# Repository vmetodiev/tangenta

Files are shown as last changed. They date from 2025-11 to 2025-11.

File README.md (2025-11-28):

# Tangenta
Micro ATX motherboard for Toradex Verdin iMX8M Mini

# Alternative Idea
To be used as a base for developing mATX motherboards for other (similar) SoMs.

# Project Features

## USB (via Microchip hub)
- 3x USB ports exposed on the rear panel - for mouse, keyboard, storage drive
- 1x USB port connects to an M.2 slot with a SIM card (for a mobile modem)

## HDMI
- LVDS to HDMI via Lontium

## Ethernet (via Realtek switch)
- 3x RJ-45 with integrated magnetics (1000BASE-T)
- 1x SFP (1000BASE-X)

## PCIe (via Pericom switch)
- 2x PCIe slots (full-length x16, operating at x1 speed, Gen 2)
- 1x M.2 slot for SSD expansion (operating at x1 speed, Gen 2)

## Industrial Connectivity
- 2x Isolated CAN transceivers
- 1x Isolated RS-422 transceiver (could be used as RS-485 as well)

All of the above exposed over a single RJ-45 connector (to fit the maximum allowed ATX rear panel lenght)

# A few images
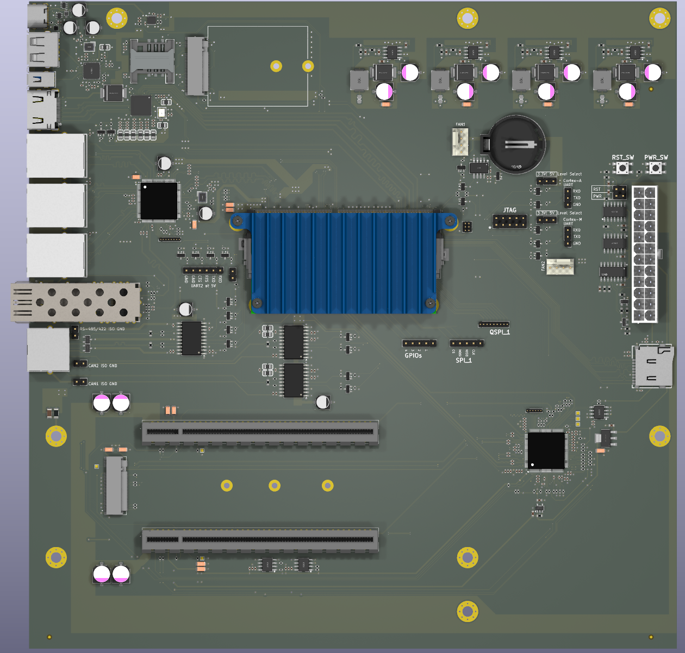
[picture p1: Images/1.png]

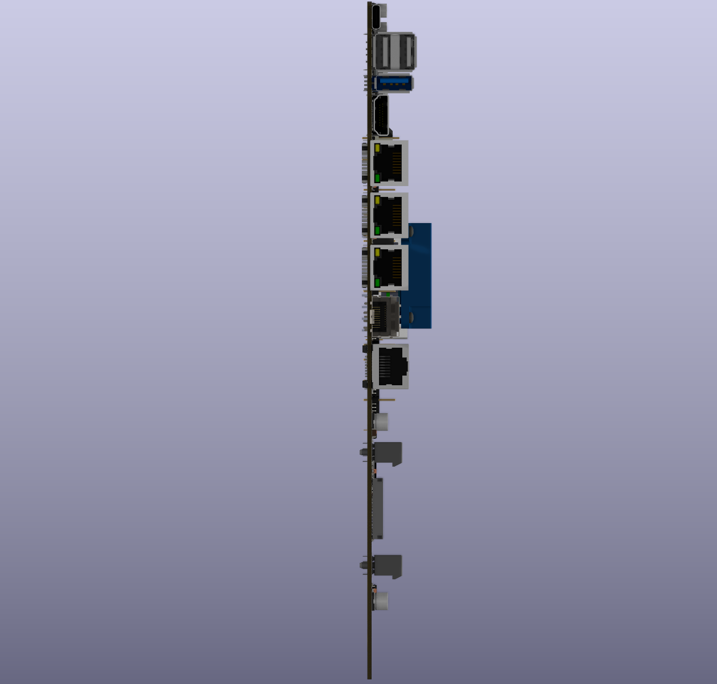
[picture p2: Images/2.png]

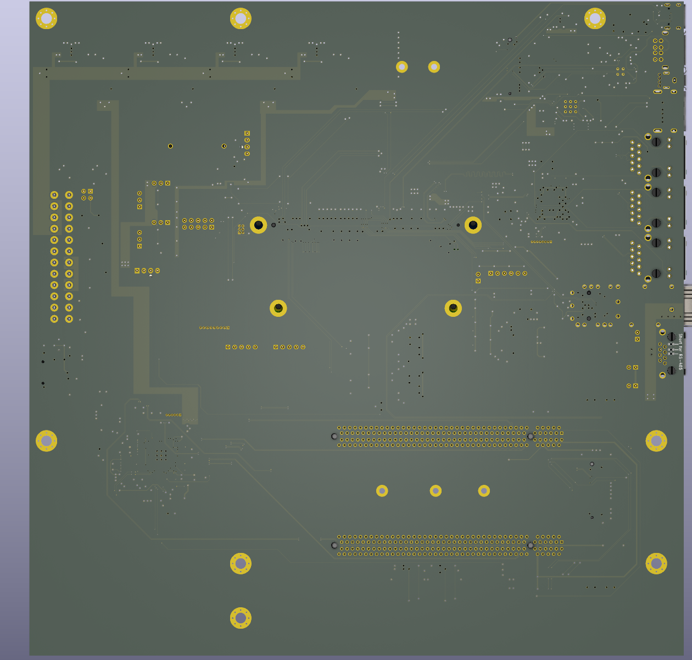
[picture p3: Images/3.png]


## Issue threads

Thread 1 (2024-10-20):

SODIMM connector - mirrored

vmetodiev, 2024-10-20:
A mirrored horizontal SODIMM DDR4 has been used in the design by mistake.

Find a real solution for the next version: moving the capacitor and the level shifter MOSFETs (the ones that are now next to the CANbus ICs) could make space for soldering a proper SODIMM (preserving the routing and the current footprint as is, at least electrically). Move the mounting holes for the heatsink as well.

Workaround: We have manually soldered a vertical SODIMM.

vmetodiev, 2024-10-20:
This is how the workaround looks like (**_many thanks to Ivan_**):
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

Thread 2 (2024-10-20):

PCIe does not come up

vmetodiev, 2024-10-20:
TorizonCore 5.7.2+build.20 verdin-imx8mm-15400884 ttymxc0

torizon@verdin-imx8mm-15400884:~$ dmesg | grep pci
[    1.249140] ehci-pci: EHCI PCI platform driver
[    1.668146] imx6q-pcie 33800000.pcie: PLL REF_CLK is used!.
[    1.671036] imx6q-pcie 33800000.pcie: PCIe PLL locked after 20 us.
[    1.902575] imx6q-pcie 33800000.pcie: host bridge /soc@0/pcie@33800000 ranges:
[    1.902605] imx6q-pcie 33800000.pcie:    IO 0x1ff80000..0x1ff8ffff -> 0x00000000
[    1.902620] imx6q-pcie 33800000.pcie:   MEM 0x18000000..0x1fefffff -> 0x18000000
[    2.895968] imx6q-pcie 33800000.pcie: Phy link never came up
[    2.895987] imx6q-pcie 33800000.pcie: failed to initialize host
[    2.901919] imx6q-pcie 33800000.pcie: unable to add pcie port.

Action plan:
1. Try with the latest TorizonOS build (prepared)
2. Analyse the schematics (the series stub and termination resistors)
3. Analyse the PCB (routing)

vmetodiev, 2024-10-20:
Link that may be useful:
https://community.toradex.com/t/pci-express-not-working-on-verdin-imx8m-plus-bsp-5/15591

https://community.nxp.com/t5/i-MX-Processors/i-MX7D-quot-pcie-phy-link-never-came-up-quot-error-110/td-p/1847850

https://community.nxp.com/t5/Processor-Expert-Software/IMX8MQ-PCIE-phy-link-never-came-up/m-p/1466563

vmetodiev, 2024-10-20:
The new TorizonOS image has been created via "**_torizoncore-builder_** build" with the following config:

$ cat tcbuild.yaml | grep -v '\#'

input:
  easy-installer:
     toradex-feed:
       version: "6.7.0"
       release: quarterly
       machine: verdin-imx8mm
       distro: torizon-upstream
       variant: torizon-core-docker
       build-number: "18"

output:
  easy-installer:
    local: output_directory

Image uploaded to Google Drive.

vmetodiev, 2025-01-05:
Error identified - TX/RX pairs between the SoM and the PCIe-SW need to be swapped.
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

vmetodiev, 2025-05-23:
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

The PCIe uplink should be crossed:

PERP[0]   --- to --- Toradex SoM TX_P
PERN[0]   --- to --- Toradex SoM TX_N

PETP[0]   --- to --- Toradex SoM RX_P
PETN[0]   --- to --- Toradex SoM RX_N

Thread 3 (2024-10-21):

Migrate the project to the latest KiCAD version

vmetodiev, 2024-10-21:
The current version was started on KiCAD 6. Migrate the project to the latest KiCAD, following the best design practices on both schematic and PCB level.

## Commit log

2023-06-21 Adding SIM card slot.
    [PseudoBOM.xls]
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2023-06-26 New ATX Power ON/OFF Schematics based on flip-flops.
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2023-07-12 Current progress, power supply.
    [ChassisButtons.kicad_sch]
2023-07-13 Adding the TPS diode.
    [ChassisButtons.kicad_sch, PowerSupply.kicad_sch]
2023-07-13 Power supply - current progress.
    [PowerSupply.kicad_sch]
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2023-07-16 PCIe x16 slots placed.
    [PCIExpressSlots.kicad_sch, Tangenta.kicad_pcb, Tangenta.kicad_sch]
2023-07-17 Setting up 4-layer stackup.
    [Tangenta.kicad_pcb]
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2023-07-21 Current progress with the USB schematics...
    [EthernetSwitch.kicad_sch, PowerSupply.kicad_sch, Tangenta.kicad_pcb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]
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2023-07-22 USB - current progress...
    [MobileModem.kicad_sch, Tangenta.kicad_pcb, Tangenta.kicad_sch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]
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2023-07-23 Fixing the SFP cage footprint.
    [EthernetSwitch.kicad_sch, Tangenta.kicad_pcb]
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2023-07-24 Adding USB current switch.
    [EthernetSwitch.kicad_sch, USB_OTG.kicad_sch]
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2023-07-24 USB DualRole in progress...
    [EthernetSwitch.kicad_sch, Tangenta.kicad_pcb, USB_OTG.kicad_sch]
2023-07-24 USB DR schematic done.
    [EthernetSwitch.kicad_sch, Tangenta.kicad_sch, Toradex.kicad_sch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]
2023-07-25 USB dual role routed.
    [EthernetSwitch.kicad_sch, PowerSupply.kicad_sch, Tangenta.kicad_pcb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]
2023-07-25 USB - minor improvements...
    [Tangenta.kicad_pcb]
2023-07-25 Starting DSI to HDMI...
    [DSI_HDMI.kicad_sch, EthernetSwitch.kicad_sch, Tangenta.kicad_sch]
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2023-07-27 Adding 25MHz oscillator.
    [DSI_HDMI.kicad_sch, EthernetSwitch.kicad_sch]
2023-07-27 Lontium - current progress...
    [DSI_HDMI.kicad_sch, EthernetSwitch.kicad_sch, Tangenta.kicad_pcb]
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2023-07-30 HDMI port I2C with level shifter.
    [DSI_HDMI.kicad_sch, Tangenta.kicad_pcb, Tangenta.kicad_sch]
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2023-07-30 Fixing the USB TypeC shield connection.
    [EthernetSwitch.kicad_sch, Tangenta.kicad_pcb]
2023-07-31 AirPrime EM7421 outlines and M2 standoff hole.
    [Tangenta.kicad_pcb]
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2023-08-01 Assemby standoffs for Verdin and cooling, M2 as well.
    [EthernetSwitch.kicad_sch, Tangenta.kicad_pcb, Toradex.kicad_sch]
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2023-08-07 Element around the Sierra Wireless M2 slot.
    [EthernetSwitch.kicad_sch, MobileModem.kicad_sch, Tangenta.kicad_pcb]
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2023-08-09 Routing 3.3V on the M2 slot of the mobile modem.
    [Tangenta.kicad_pcb]
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2023-08-10 Adding 3V3 standby for the PCIe
    [EthernetSwitch.kicad_sch, PowerSupply.kicad_sch, Tangenta.kicad_pcb]
2023-08-10 PCIe current progress, hierarchy
    [EthernetSwitch.kicad_sch, PCIE_Switch.kicad_sch, PCIExpress.kicad_sch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]
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2023-08-12 PCIe RESET level shifter.
    [EthernetSwitch.kicad_sch, Toradex.kicad_sch]
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2023-08-14 Fixing the PCIe switch symbol and grid alignment.
    [EthernetSwitch.kicad_sch, PCIE_Switch.kicad_sch]
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2023-08-16 PCIe switch schematic, continued...
    [EthernetSwitch.kicad_sch, PCIE_Slot_1.kicad_sch, PCIE_Slot_2.kicad_sch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]
2023-08-17 PCIe switch schematic done.
    [EthernetSwitch.kicad_sch, PCIE_Switch.kicad_sch]
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2023-08-20 PCIe at Toradex side; handling unconnected pins.
    [ChassisButtons.kicad_sch, EthernetSwitch.kicad_sch, PowerSupply.kicad_sch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]
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2023-08-21 PCIe switch components placement, current progress...
    [EthernetSwitch.kicad_sch, Tangenta.kicad_pcb]
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2023-08-21 Adding the remaining PCIe nets.
    [EthernetSwitch.kicad_sch, PCIE_Switch.kicad_sch, Tangenta.kicad_pcb]
2023-08-22 PCIe switch fanout, in progress...
    [EthernetSwitch.kicad_sch, PCIE_Switch.kicad_sch, Tangenta.kicad_pcb]
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2023-08-23 PCIE slot 1 - lengths matched.
    [Tangenta.kicad_pcb]
2023-08-23 Fixing PCIE lane 1 trace tuning.
    [Tangenta.kicad_pcb]
2023-08-24 PCIe downlink equalised, TBD: uplink
    [Tangenta.kicad_pcb]
2023-08-24 PCIe lenghts now equal.
    [Tangenta.kicad_pcb]
2023-08-25 PCIe 3V3 ground decaps done.
    [Tangenta.kicad_pcb]
2023-08-25 PCIe ready for review.
    [Tangenta.kicad_pcb]
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2023-08-28 Ethernet switch net labels.
    [EthernetSwitch.kicad_sch, Ethernet_RJ45_Port_1.kicad_sch, Ethernet_RJ45_Port_2.kicad_sch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]
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2023-08-29 Ethernet Switch schematic done, ports TBD...
    [Ethernet.kicad_sch, Ethernet_RJ45_Port_1.kicad_sch, Ethernet_RJ45_Port_2.kicad_sch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]
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2023-08-31 Ethernet, SFP to be done...
    [Ethernet_RJ45_Port_2.kicad_sch, Ethernet_RJ45_Port_3.kicad_sch, Tangenta.kicad_pcb]
2023-09-01 Ethernet ready for routing.
    [Ethernet.kicad_sch, Ethernet_SFP_Port_4.kicad_sch, Tangenta.kicad_pcb]
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2023-09-25 CANbus current progress, RS-422 with 0603 termination resistor.
    [CAN_Channel_1.kicad_sch, CAN_Channel_2.kicad_sch, RS_485_422.kicad_sch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]
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2023-10-10 SoM power and GND schematic and routing, TBD: power planes
    [Tangenta.kicad_pcb, Toradex.kicad_sch]
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2023-11-09 Removing drl files in milimeters to avoid confusion at JLCPCB...
    [Tangenta-NPTH-mm.drl, Tangenta-PTH-mm.drl]
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2023-11-15 Adding BOM and POS files in Excel format.
    [Chola-BOM_JLCSMT.xlsx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]
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2024-04-02 Fixing PCIe power planes and tracks.
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2024-10-20 Adding pick and place, BOM to be edited when Mouser parts arrive at JLC.
    [Tangenta-top-pos-excel-2024.xlsx]
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2024-10-20 Fixing fans rotation inside PnP.
    [Tangenta-PnP-2024.xlsx]
2024-10-20 BOM upted with the Mouser and consigned parts.
    [Tangenta-BOM-2024.xlsx]
2024-10-20 Adding the 3rd party components to BOM with their JLC part numbers.
    [Tangenta-BOM-2024.xlsx]
2024-10-20 New capacitor part number for the TPS buck regulators.
    [Tangenta-BOM-2024.xlsx]
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2025-05-23 Tidying up the mess, placing the downloaded BOM after the successful prototype manufacturing.
    [BOM.csv, Tangenta-BOM-2024.xlsx, Tangenta-BOM.xls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]
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2025-11-24 Moving the TPS from the local to the global lib.
    [PowerSupply.kicad_sch]
2025-11-24 Fixing the issues caused by the git merge.
    [CAN_Channel_1.kicad_sch, CAN_Channel_2.kicad_sch, CANbus.kicad_sch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]
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2025-11-25 Removing component association with previous project (local) libraries.
    [CAN_Channel_1.kicad_sch, CAN_Channel_2.kicad_sch, CANbus.kicad_sch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]
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2025-11-26 Fixes, continued...
    [CAN_Channel_1.kicad_sch, CAN_Channel_2.kicad_sch, ChassisButtons.kicad_sch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]
2025-11-26 Fixes, before checks.
    [CAN_Channel_1.kicad_sch, CAN_Channel_2.kicad_sch, CANbus.kicad_sch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]
2025-11-26 Reverting to the original design.
    [CAN_Channel_1.kicad_sch, CAN_Channel_2.kicad_sch, CANbus.kicad_sch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]
2025-11-26 Fixes, new approach.
    [CAN_Channel_1.kicad_sch, CAN_Channel_2.kicad_sch, CANbus.kicad_sch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]
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2025-11-27 SODIMM connector fixed.
    [Toradex.kicad_sch]
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2025-11-27 SODIMM connector fix, routing optimisations.
2025-11-27 Fixing trace width.
2025-11-27 PCIe fix in progress...
    [PCIExpress.kicad_sch, Tangenta.kicad_sch]
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2025-11-28 Implemented inverted ATX power button (optional).
    [ChassisButtons.kicad_sch]
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
